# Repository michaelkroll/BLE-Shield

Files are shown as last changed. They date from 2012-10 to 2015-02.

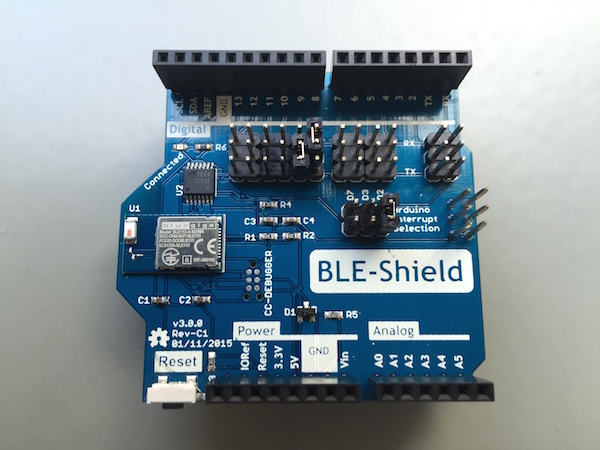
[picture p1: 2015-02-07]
docs/BLE-Shieldv3C1.jpg

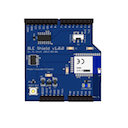
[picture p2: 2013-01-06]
iphone/BLE-Shield/BLE-Shield/ble-shield-list.png

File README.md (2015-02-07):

## BLE-Shield

The MIT License (MIT)
Copyright (c) 2012-2015 Dr. Michael Kroll
 
Permission is hereby granted, free of charge, to any person obtaining a copy of this software and associated 
documentation files (the "Software"), to deal in the Software without restriction, including without limitation 
the rights to use, copy, modify, merge, publish, distribute, sublicense, and/or sell copies of the Software, 
and to permit persons to whom the Software is furnished to do so, subject to the following conditions:
 
The above copyright notice and this permission notice shall be included in all copies or substantial portions of the Software.
 
THE SOFTWARE IS PROVIDED "AS IS", WITHOUT WARRANTY OF ANY KIND, EXPRESS OR IMPLIED, INCLUDING BUT NOT 
LIMITED TO THE WARRANTIES OF MERCHANTABILITY, FITNESS FOR A PARTICULAR PURPOSE AND NONINFRINGEMENT. IN 
NO EVENT SHALL THE AUTHORS OR COPYRIGHT HOLDERS BE LIABLE FOR ANY CLAIM, DAMAGES OR OTHER LIABILITY, 
WHETHER IN AN ACTION OF CONTRACT, TORT OR OTHERWISE, ARISING FROM, OUT OF OR IN CONNECTION WITH THE 
SOFTWARE OR THE USE OR OTHER DEALINGS IN THE SOFTWARE.

### Content

This repository contains the eagle design files as well as the firmware source code and precompiled hex files.
Moreover I added the Arduino Sketches from my blog to this repository.

### Latest Version

The Latest version of the BLE-Shield is v3.0.0 as illustrated in the image below.

(https://raw.github.com/michaelkroll/BLE-Shield/master/docs/BLE-Shieldv3C1.jpg)

#### Services and Characteristics of the BLE-Shield v3.0.0

The new BLE-Shield supports some new services and haracteristics. The RX and TX characteristics are not combined into one indicating Data characteristic
Moreover the Bluegiga OTA Service is supported enabling you to update the BLE-Shield over the air using e.g. the iOS App BLExplr.

##### BLE-Shield Service v3.0.0 (B4BDB998-8F4A-45F6-A407-6B48D79CFC2F)

###### Bluetooth Device Address Characteristic (B4BDB998-8F4B-45F6-A407-6B48D79CFC2F)

This characteristic is read only and used to retrieve the Bluetooth Device Address of the BLE113-M256k module.

###### Baudrate Characteristic (B4BDB998-8F4C-45F6-A407-6B48D79CFC2F)

This characteristic is read and write and used to set the BLE-Shields baudrate. The default baudrate is 9600 baud
It is a one byte characteristic. The following baudrates are suported and can be set using the following byte set to the
characteristic:

Baudrate  | Configuration Byte
--------- | ------------------
9600      | 0x00
14400     | 0x01
19200     | 0x02
28800     | 0x03
38400     | 0x04
57600     | 0x05
115200    | 0x06

###### Enable Connect LED characteristic (B4BDB998-8F4D-45F6-A407-6B48D79CFC2F)

This characteristic is used to control the connection LED on the BLE-Shield. The LED is per default off.
In order to change it's behavior write e.g. 0xff the the characteristic to make it lit on the next connection.

LED State | Configuration Byte
--------- | ------------------
OFF       | 0x00
ON        | 0xff

###### Data characteristic (B4BDB998-8F4E-45F6-A407-6B48D79CFC2F)

The new BLE-Shield v3.0.0 uses a Data characteristic to send and receive data. In order to support this
the characteristic is a write and indicate characteristic. On BLExplr it is no longer necessary to switch between
RX and TX characteristics. You can stay on the same screen to see data which is recevied while you are transmitting data.

##### Bluegiga OTA Service (1d14d6ee-fd63-4fa1-bfa4-8f47b42119f0)

This is the implementation of Bluegiga's OTA Service to update the firmware over the air.

###### Data characteristic (f7bf3564-fb6d-4e53-88a4-5e37e0326063)

Bluegiga OTA Control Characteristic

###### Data characteristic (984227f3-34fc-4045-a5d0-2c581f81a153)

Bluegiga OTA Data Characteristic

### Links
* http://www.mkroll.mobi
* http://forum.mkroll.mobi

### Notes:
* The Eagle design files are created using Eagle v5.11.0 - v7.1 depending on the version of the BLE-Shield. BLE-Shield v3.0.0 was designed with Eagle v7.1.0
* The Firmware v1.0.0 and v1.0.1 for the BLE112 module on the BLE-Shield was created and compiled for the Bluegiga BLE112 SDK v1.0.3 Build 43
* The Firmware v3.0.0 was developed using Bluegiga's BLE SDK v1.3.2 Build 122.
* The Arduino Sketches have been tested with Arduino 1.0.1
* the Arduino Sketched vor BLE-Shield v3.0.0 has been tested with Arduino v1.0.6 on OSX
* The .NETMF Sample has been tested with Microsoft Visual C# Express 2010, .NET Micro Framework SDK v4.2 and the Netduino SDK v4.2.2.0 (32-bit) running on a NetDuino2

## .NETMF support 
The latest addition to this repository is .NETMF support. With a little help of Thomas Amberg @tamberg I added a sample project for 
the NetDuino2 board available at http://www.netduino.com which shows how use the BLE-Shield with this platform.  

## BLE-Shield iPhone App for the BLE-Shield v1.0.0

The iPhone App was part of the BLE-Shield Kickstarter campaign https://www.kickstarter.com/projects/rowdyrobot/arduino-ble-shield-connecting-the-ios-and-the-ardu and only
supports the BLE-Shield v1.0.0 The BLE-Shield app provides access to the BLE-Shield Service and their characteristics. It's user interface is implemented like 
a chat application. The chart partners are the BLE-Shield and the iPhone, illustrated by small icons.

Once the BLE-Shield is connected, the application will automatically enable notifications on the RX characteristic. So whenever 
the BLE-Shield's 16 byte buffer is filled completely, the buffer will be notified to the iPhone. 

The app was developed using Xcode 4.5.2, iOS6 SDK and tested on an iPhone4S and iPhone5 running iOS6.0.1

*Screenshots*

 
. 
. 
. 
. 
. 
. 

### Used third party components

* BLEUtils taken from the TI SensorTag App, created by Ole Andreas Torvmark 
* MBProgressHUD created by Matej Bukovinski https://github.com/matej/MBProgressHUD
* PTSMessagingCell created by Ralph Grasser https://github.com/ppanopticon/PTSMessagingCell/

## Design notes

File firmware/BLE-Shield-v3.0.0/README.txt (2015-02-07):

The BLE113 pins are used as follows:
--------------------------------------------------

TX                 P0_4
RX                 P0_5

Connected LED      P0_0
Interrupt Pin      P0_1

--------------------------------------------------

The firmware is compiled against v 1.3.2 build 122

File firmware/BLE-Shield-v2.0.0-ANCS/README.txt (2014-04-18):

The BLE112 pins are used as follows:
--------------------------------------------------

TX                 P0_4
RX                 P0_5

Connected LED      P0_0
Interrupt Pin      P0_1

BLE Host Wakeup    P1_5
BLE Modules Wakeup P1_6

USB Port           P1_0
Boot to DFU        P1_1
--------------------------------------------------

The firmware is compiled against v 1.2.2 build 100

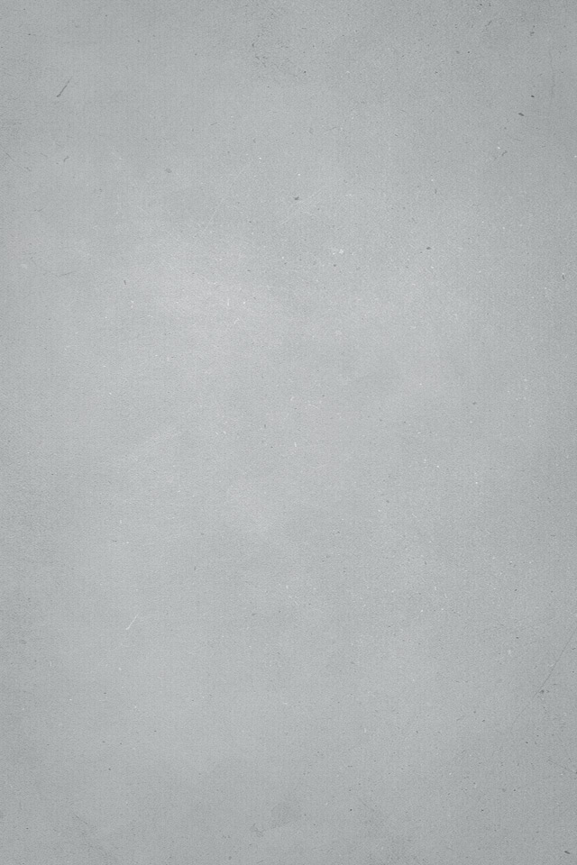
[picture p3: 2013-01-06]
iphone/BLE-Shield/BLE-Shield/background@2x.png

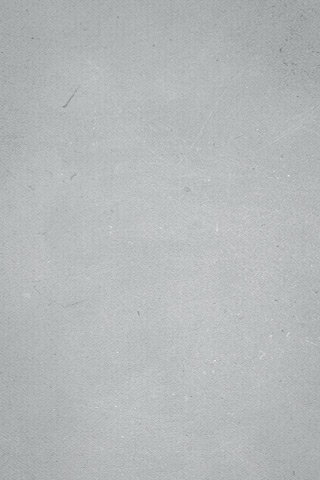
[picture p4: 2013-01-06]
iphone/BLE-Shield/BLE-Shield/background.png

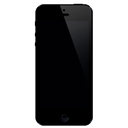
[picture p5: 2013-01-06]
iphone/BLE-Shield/BLE-Shield/iphone.png

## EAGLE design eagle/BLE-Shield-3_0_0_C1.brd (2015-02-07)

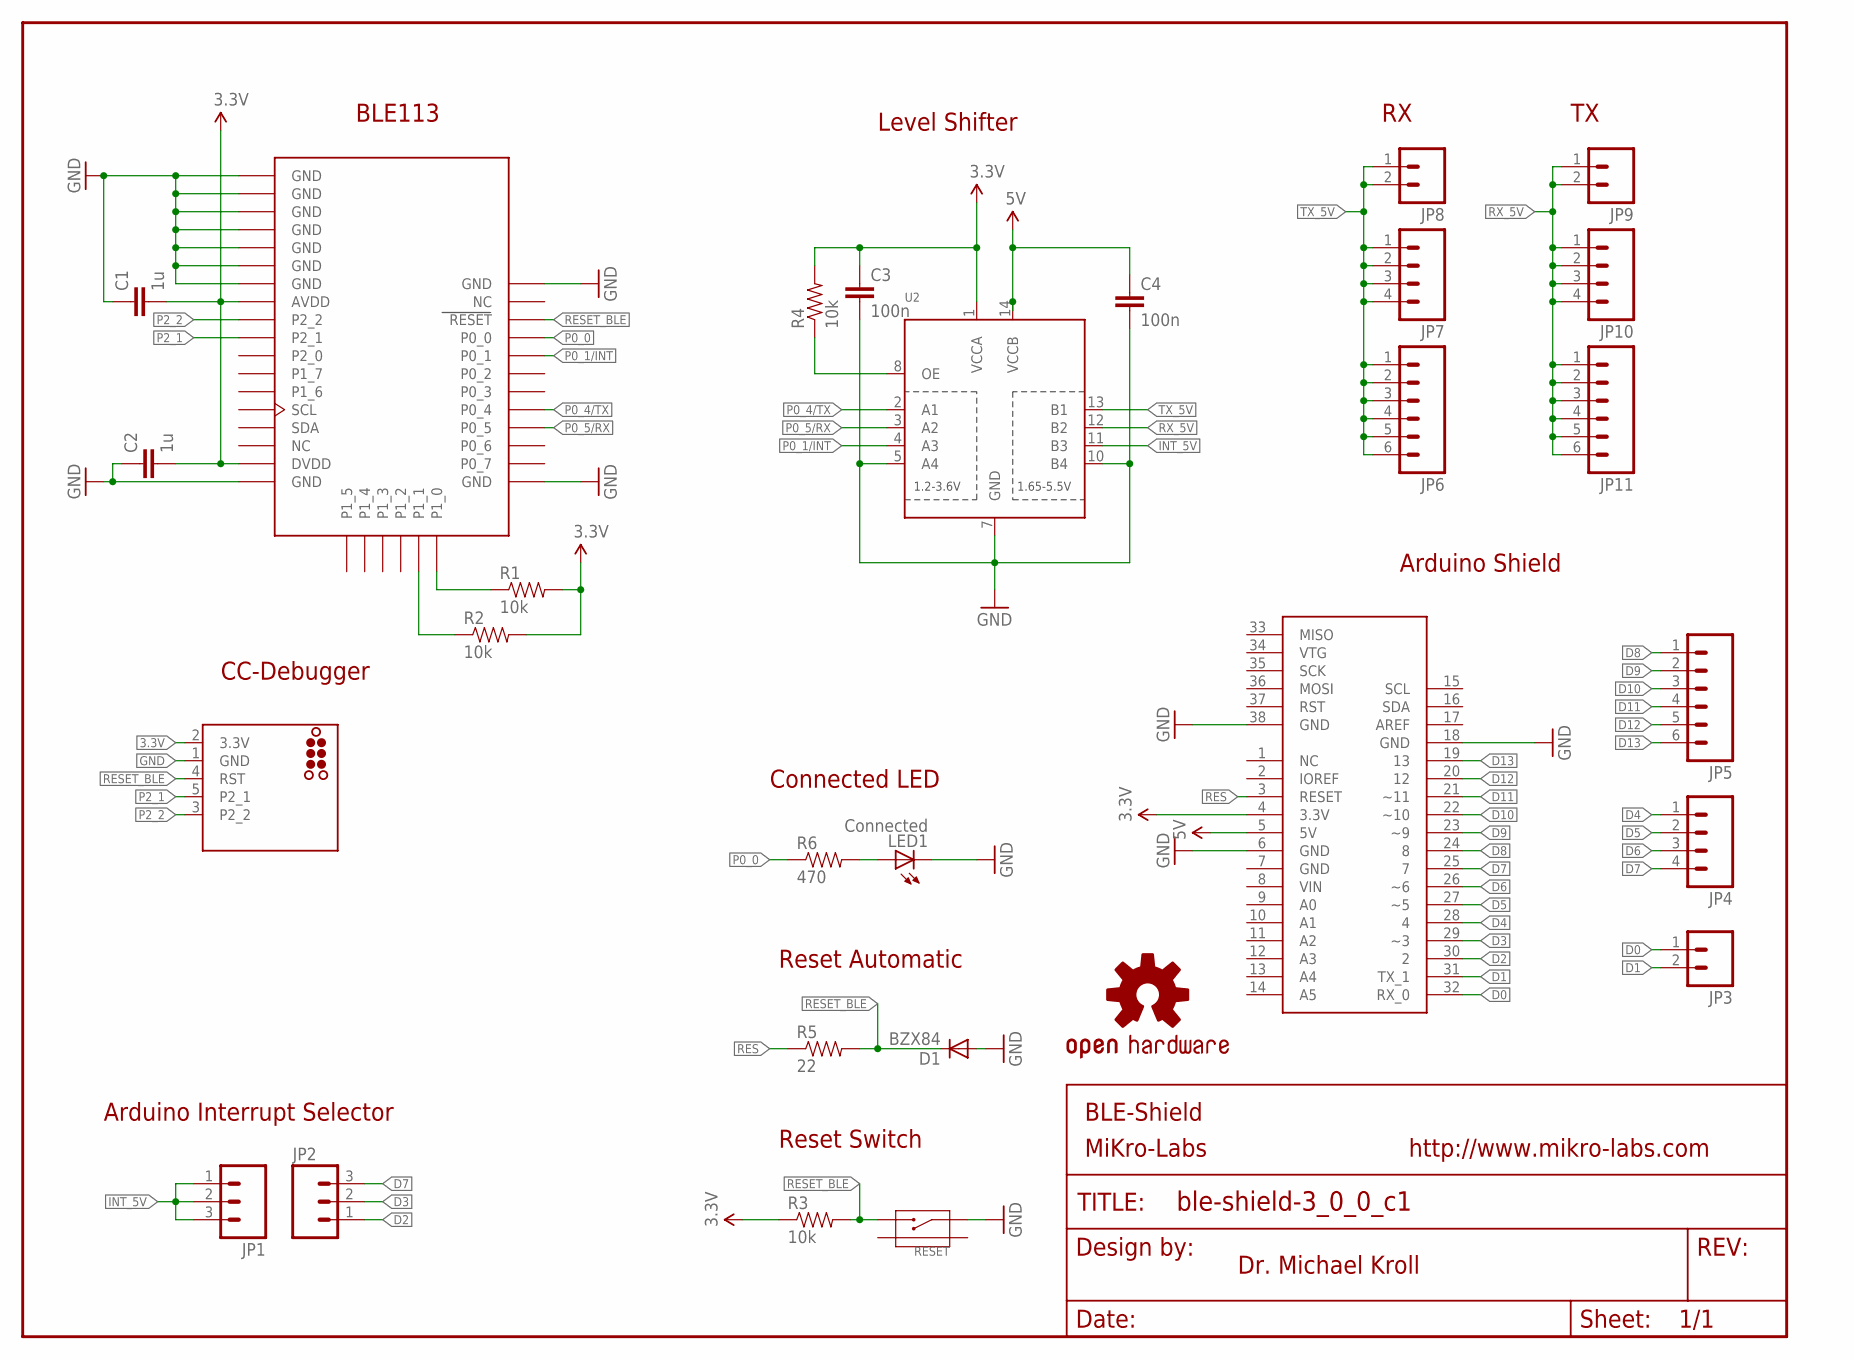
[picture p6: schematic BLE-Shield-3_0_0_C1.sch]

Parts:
C1, C2: 1u; 0603-CAP
C3, C4: 100n; 0603-CAP
CC-DEBUGGER: TC2030-CC-DEBUGGER; TC2030-MCP-NL
D1: BZX84; SOT23-3
FRAME1: FRAME-LETTER; CREATIVE_COMMONS
JP1, JP2: M03PTH; 1X03
JP3, JP8, JP9: M02PTH; 1X02
JP4, JP7, JP10: M04PTH; 1X04
JP5, JP6, JP11: M06SIP; 1X06
LED1: Connected; LED-0603
LOGO1: OSHW-LOGOS; OSHW-LOGO-S
R1, R2, R3, R4: 10k; 0603-RES
R5: 22; 0603-RES
R6: 470; 0603-RES
RESET: BUTTON-2P-REINFORCE-3100060P1; 4P-SMD-7.0X3.5X3.5H-90D
U1: BLE113-A-VISUAL; BLE113-A
U2: TXB0104PWR; TSSOP14
U$1: ARDUINO_UNO_SHIELD_ICSP_PADS_ONLY; ICSP_PADS_ONLY

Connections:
3.3V: C1.2, C2.2, C3.1, CC-DEBUGGER.2 (3.3V), R1.2, R2.2, R3.1, R4.2, U1.AVDD, U1.DVDD, U2.1 (VCCA), U$1.4 (3.3V)
5V: C4.1, U2.14 (VCCB), U$1.5 (5V)
D0: JP3.1, U$1.32 (RX_0)
D1: JP3.2, U$1.31 (TX_1)
D2: JP2.1, U$1.30 (2)
D3: JP2.2, U$1.29 (~3)
D4: JP4.1, U$1.28 (4)
D5: JP4.2, U$1.27 (~5)
D6: JP4.3, U$1.26 (~6)
D7: JP2.3, JP4.4, U$1.25 (7)
D8: JP5.1, U$1.24 (8)
D9: JP5.2, U$1.23 (~9)
D10: JP5.3, U$1.22 (~10)
D11: JP5.4, U$1.21 (~11)
D12: JP5.5, U$1.20 (12)
D13: JP5.6, U$1.19 (13)
GND: C1.1, C2.1, C3.2, C4.2, CC-DEBUGGER.1 (GND), D1.1 (A), LED1.C, RESET.1, U1.GND, U1.GND@2 (GND), U1.GND@3 (GND), U1.GND@4 (GND), U1.GND@5 (GND), U1.GND@6 (GND), U1.GND@7 (GND), U1.GND@8 (GND), U1.GND@9 (GND), U1.GND@10 (GND), U2.5 (A4), U2.7 (GND), U2.10 (B4), U$1.6 (GND), U$1.18 (GND), U$1.38 (GND)
INT_5V: JP1.1, JP1.2, JP1.3, U2.11 (B3)
unnamed: LED1.A, R6.2
unnamed: R4.1, U2.8 (OE)
unnamed: R1.1, U1.P1_0
unnamed: R2.1, U1.P1_1
P0_0: R6.1, U1.P0_0
P0_1/INT: U1.P0_1, U2.4 (A3)
P0_4/TX: U1.P0_4, U2.2 (A1)
P0_5/RX: U1.P0_5, U2.3 (A2)
P2_1: CC-DEBUGGER.5 (P2_1), U1.P2_1
P2_2: CC-DEBUGGER.3 (P2_2), U1.P2_2
RES: R5.1, U$1.3 (RESET)
RESET_BLE: CC-DEBUGGER.4 (RST), D1.3 (C), R3.2, R5.2, RESET.2, U1.RESET
RX_5V: JP9.1, JP9.2, JP10.1, JP10.2, JP10.3, JP10.4, JP11.1, JP11.2, JP11.3, JP11.4, JP11.5, JP11.6, U2.12 (B2)
TX_5V: JP6.1, JP6.2, JP6.3, JP6.4, JP6.5, JP6.6, JP7.1, JP7.2, JP7.3, JP7.4, JP8.1, JP8.2, U2.13 (B1)

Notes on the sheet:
BLE113
CC-Debugger
Arduino Shield
Level Shifter
Reset Switch
Reset Automatic
Connected LED
Arduino Interrupt Selector
BLE-Shield
MiKro-Labs
http://www.mikro-labs.com
Dr. Michael Kroll

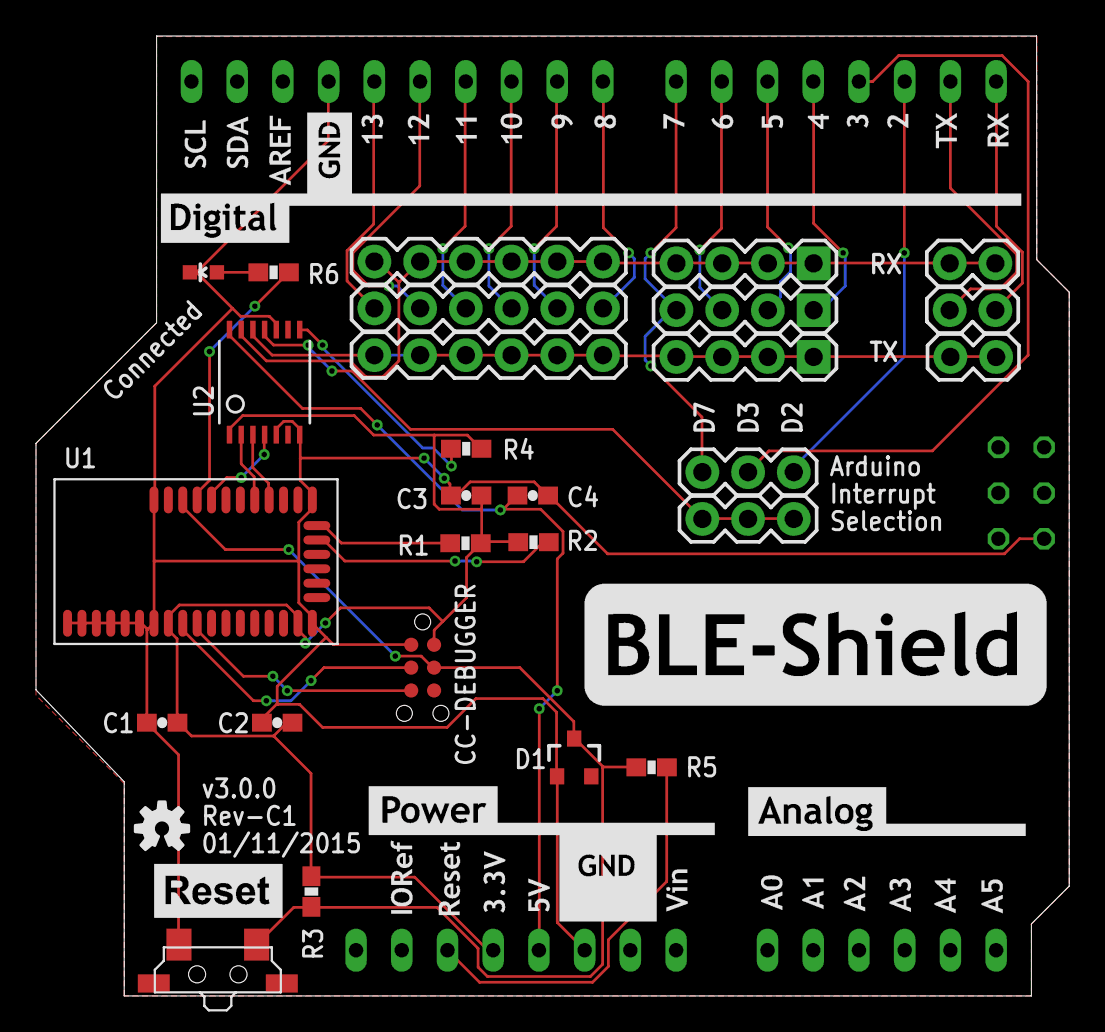
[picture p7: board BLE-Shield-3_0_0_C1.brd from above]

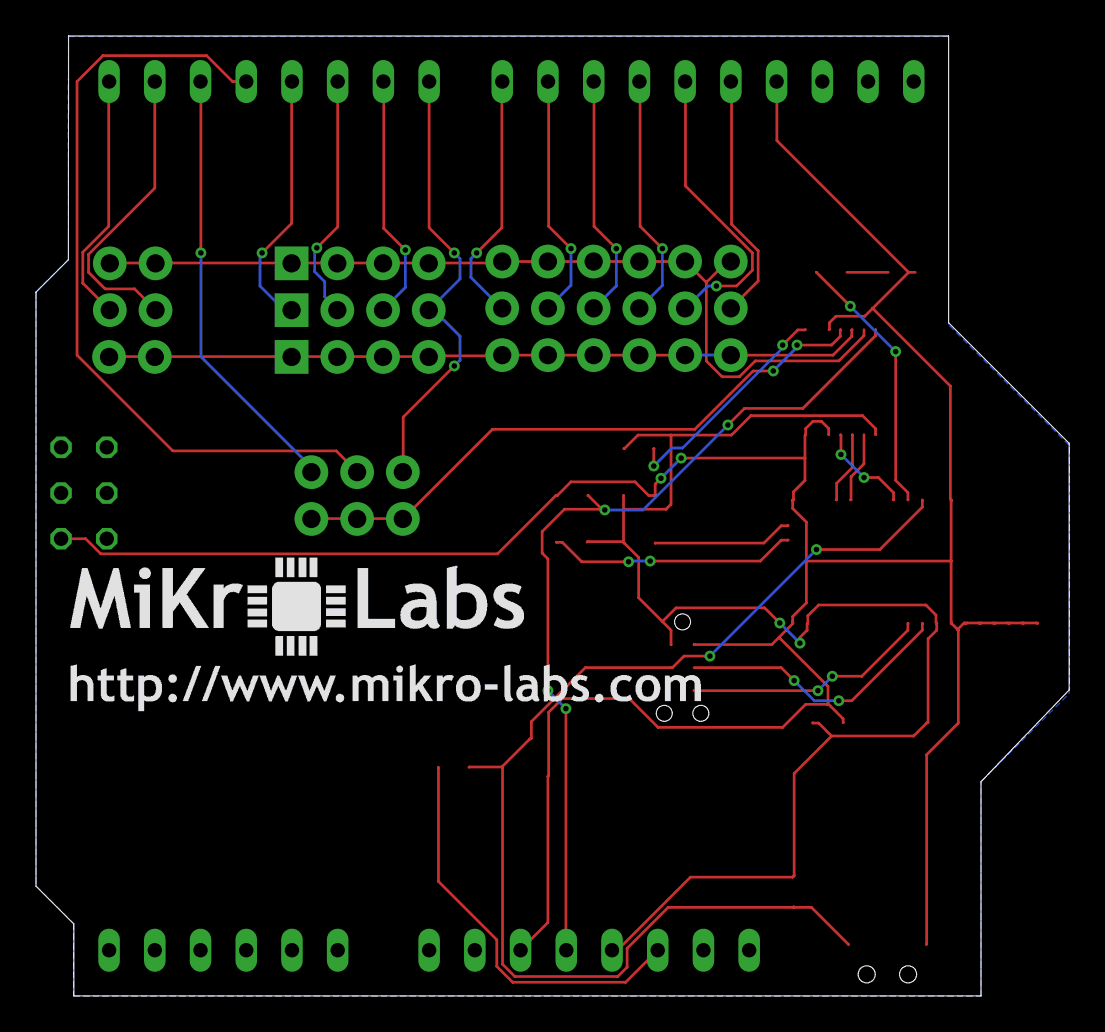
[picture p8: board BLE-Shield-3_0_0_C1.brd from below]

Board: 4 copper layers, 57.4 x 53.3 mm, 36 parts (2 on the bottom side), 32 nets.

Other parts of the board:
U$2: DIGITAL
U$3: POWER-ANALOG
U$4: MIKROLABS-URL
U$5: MIKROLABS-LOGO
U$6: BLE-SHIELD
U$7: RESET

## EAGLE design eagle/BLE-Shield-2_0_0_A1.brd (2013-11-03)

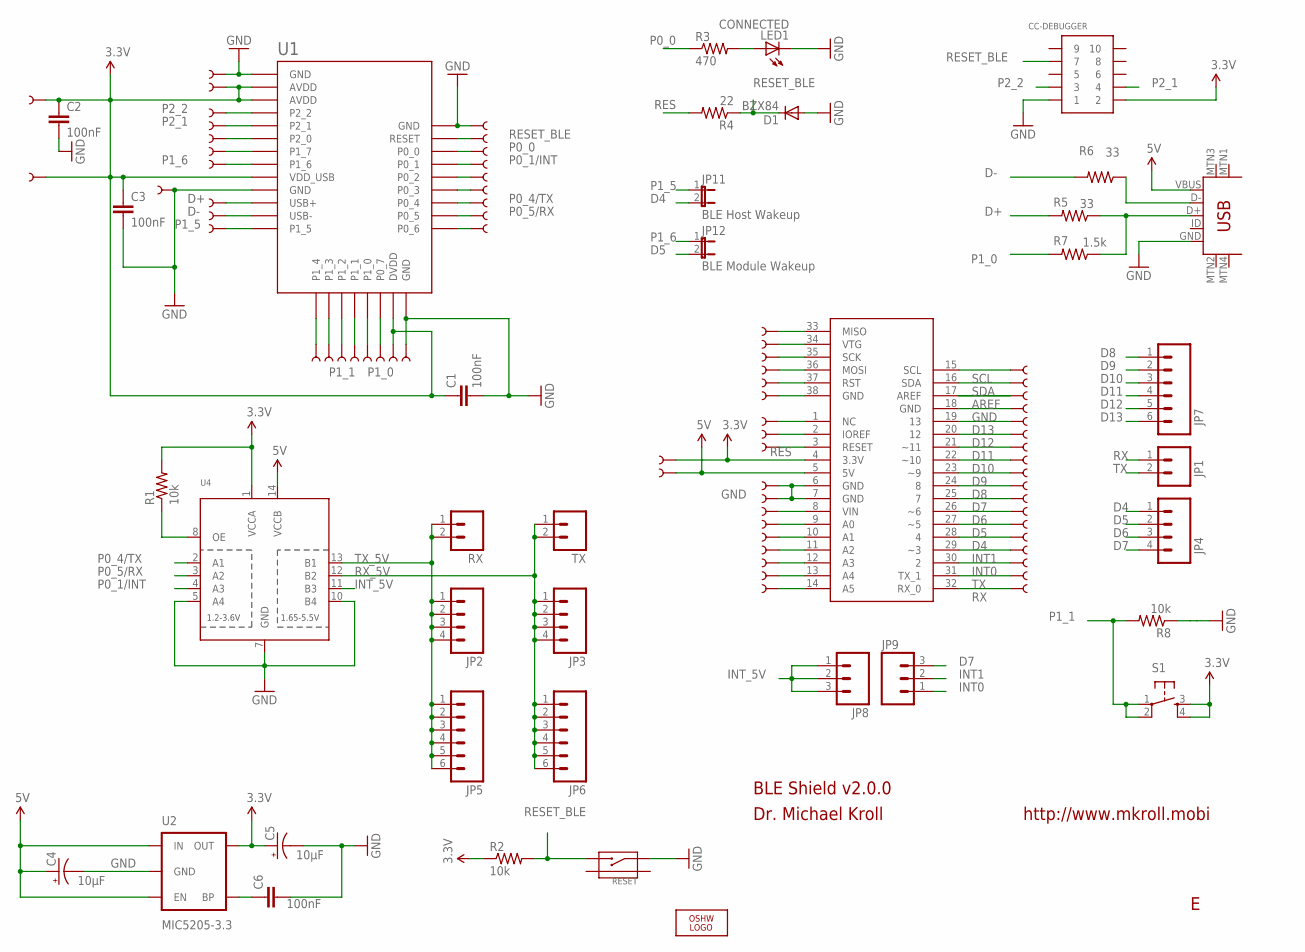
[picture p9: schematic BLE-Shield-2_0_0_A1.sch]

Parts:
C1, C2, C3, C6: 100nF; 0603-CAP
C4, C5: 10µF; EIA3216
CC-DEBUGGER: CONN_5-2-FTSH-V; FTSH-105-DV
D1: BZX84; SOT23-3
JP1: M02PTH; 1X02
JP2, JP3, JP4: M04PTH; 1X04
JP5, JP6, JP7: M06SIP; 1X06
JP8, JP9: M03PTH; 1X03
JP11: BLE Host Wakeup; SJ_2S-NO-NS
JP12: BLE Module Wakeup; SJ_2S-NO-NS
LED1: CONNECTED; LED-0603
LOGO1: LOGO-OSHW-FILLX0200-NT; OSHW_FILLX200_NOTEXT
R1, R2, R8: 10k; 0603-RES
R3: 470; 0603-RES
R4: 22; 0603-RES
R5, R6: 33; 0603-RES
R7: 1.5k; 0603-RES
RESET: BUTTON-2P-REINFORCE-3100060P1; 4P-SMD-7.0X3.5X3.5H-90D
RX: M02PTH; 1X02
S1: TAC_SWITCHSMD; TACTILE_SWITCH_SMD
TP1, TP2, TP3, TP4, TP5, TP6, TP7, TP8, TP9, TP10, TP11, TP12, TP13, TP14, TP15, TP16, TP17, TP18, TP19, TP20, TP21, TP22, TP23, TP24, TP25, TP26, TP27, TP28, TP29, TP30, TP31, TP32, TP33, TP34, TP35, TP36, TP37, TP38, TP39, TP40, TP41, TP42, TP43, TP44, TP45, TP46, TP47, TP48, TP49, TP50, TP51, TP52, TP53, TP54, TP55, TP56, TP57, TP58, TP59, TP60, TP61, TP62, TP63, TP64, TP65, TP66, TP67, TP68: TEST-POINT3X5; PAD.03X.05
TX: M02PTH; 1X02
U1: BLE112-A-VISUAL; BLE112-A
U2: MIC5205-3.3; SOT23-5
U4: TXB0104PWR; TSSOP14
U$5: ARDUINO_UNO_SHIELD_ICSP_PADS_ONLY; ICSP_PADS_ONLY
U$6: USB-MINIB-5PIN; USB-MINIB

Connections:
3.3V: C1.1, C2.1, C3.1, C5.A (+), CC-DEBUGGER.2, R1.2, R2.1, S1.3, S1.4, TP29.P$1, TP45.P$1, TP57.P$1, TP58.P$1, TP64.P$1, U1.AVDD1 (AVDD), U1.AVDD2 (AVDD), U1.DVDD, U1.VDD_USB, U2.5 (OUT), U4.1 (VCCA), U$5.4 (3.3V)
5V: C4.A (+), TP46.P$1, U2.1 (IN), U2.3 (EN), U4.14 (VCCB), U$5.5 (5V), U$6.VBUS
AREF: TP3.P$1, U$5.17 (AREF)
D4: JP4.1, JP11.2, TP14.P$1, U$5.28 (4)
D5: JP4.2, JP12.2, TP13.P$1, U$5.27 (~5)
D6: JP4.3, TP12.P$1, U$5.26 (~6)
D7: JP4.4, JP9.3, TP11.P$1, U$5.25 (7)
D8: JP7.1, TP10.P$1, U$5.24 (8)
D9: JP7.2, TP9.P$1, U$5.23 (~9)
D10: JP7.3, TP8.P$1, U$5.22 (~10)
D11: JP7.4, TP7.P$1, U$5.21 (~11)
D12: JP7.5, TP6.P$1, U$5.20 (12)
D13: JP7.6, TP5.P$1, U$5.19 (13)
D+: R5.2, TP66.P$1, U1.USB+
D-: R6.2, TP67.P$1, U1.USB-
GND: C1.2, C2.2, C3.2, C4.C (-), C5.C (-), C6.2, CC-DEBUGGER.1, D1.1 (A), LED1.C, R8.1, RESET.1, TP4.P$1, TP19.P$1, TP28.P$1, TP47.P$1, TP48.P$1, TP54.P$1, TP65.P$1, U1.GND1 (GND), U1.GND2 (GND), U1.GND3 (GND), U1.GND4 (GND), U2.2 (GND), U4.5 (A4), U4.7 (GND), U4.10 (B4), U$5.6 (GND), U$5.7 (GND), U$5.18 (GND), U$6.GND
INT0: JP9.1, TP16.P$1, U$5.30 (2)
INT1: JP9.2, TP15.P$1, U$5.29 (~3)
INT_5V: JP8.1, JP8.2, JP8.3, U4.11 (B3)
unnamed: TP53.P$1, U$5.12 (A3)
unnamed: C6.1, U2.4 (BP)
unnamed: TP56.P$1, U$5.14 (A5)
unnamed: LED1.A, R3.2
unnamed: TP55.P$1, U$5.13 (A4)
unnamed: TP52.P$1, U$5.11 (A2)
unnamed: TP51.P$1, U$5.10 (A1)
unnamed: TP50.P$1, U$5.9 (A0)
unnamed: TP49.P$1, U$5.8 (VIN)
unnamed: R5.1, R7.1, U$6.D+
unnamed: TP43.P$1, U$5.2 (IOREF)
unnamed: TP27.P$1, U1.P0_6
unnamed: TP35.P$1, U1.P1_4
unnamed: TP24.P$1, U1.P0_3
unnamed: TP23.P$1, U1.P0_2
unnamed: TP42.P$1, U$5.1 (NC)
unnamed: TP34.P$1, U1.P1_3
unnamed: TP33.P$1, U1.P1_2
unnamed: TP30.P$1, U1.P0_7
unnamed: TP41.P$1, U$5.38 (GND)
unnamed: TP40.P$1, U$5.37 (RST)
unnamed: TP39.P$1, U$5.36 (MOSI)
unnamed: TP38.P$1, U$5.35 (SCK)
unnamed: TP37.P$1, U$5.34 (VTG)
unnamed: TP36.P$1, U$5.33 (MISO)
unnamed: R6.1, U$6.D-
unnamed: TP61.P$1, U1.P2_0
unnamed: TP62.P$1, U1.P1_7
unnamed: R1.1, U4.8 (OE)
P0_0: R3.1, TP21.P$1, U1.P0_0
P0_1/INT: TP22.P$1, U1.P0_1, U4.4 (A3)
P0_4/TX: TP25.P$1, U1.P0_4, U4.2 (A1)
P0_5/RX: TP26.P$1, U1.P0_5, U4.3 (A2)
P1_0: R7.2, TP31.P$1, U1.P1_0
P1_1: R8.2, S1.1, S1.2, TP32.P$1, U1.P1_1
P1_5: JP11.1, TP68.P$1, U1.P1_5
P1_6: JP12.1, TP63.P$1, U1.P1_6
P2_1: CC-DEBUGGER.4, TP60.P$1, U1.P2_1
P2_2: CC-DEBUGGER.3, TP59.P$1, U1.P2_2
RES: R4.2, TP44.P$1, U$5.3 (RESET)
RESET_BLE: CC-DEBUGGER.7, D1.3 (C), R2.2, R4.1, RESET.2, TP20.P$1, U1.RESET
RX: JP1.1, TP18.P$1, U$5.32 (RX_0)
RX_5V: JP3.1, JP3.2, JP3.3, JP3.4, JP6.1, JP6.2, JP6.3, JP6.4, JP6.5, JP6.6, TX.1, TX.2, U4.12 (B2)
SCL: TP1.P$1, U$5.15 (SCL)
SDA: TP2.P$1, U$5.16 (SDA)
TX: JP1.2, TP17.P$1, U$5.31 (TX_1)
TX_5V: JP2.1, JP2.2, JP2.3, JP2.4, JP5.1, JP5.2, JP5.3, JP5.4, JP5.5, JP5.6, RX.1, RX.2, U4.13 (B1)

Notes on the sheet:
BLE Shield v2.0.0
Dr. Michael Kroll
http://www.mkroll.mobi

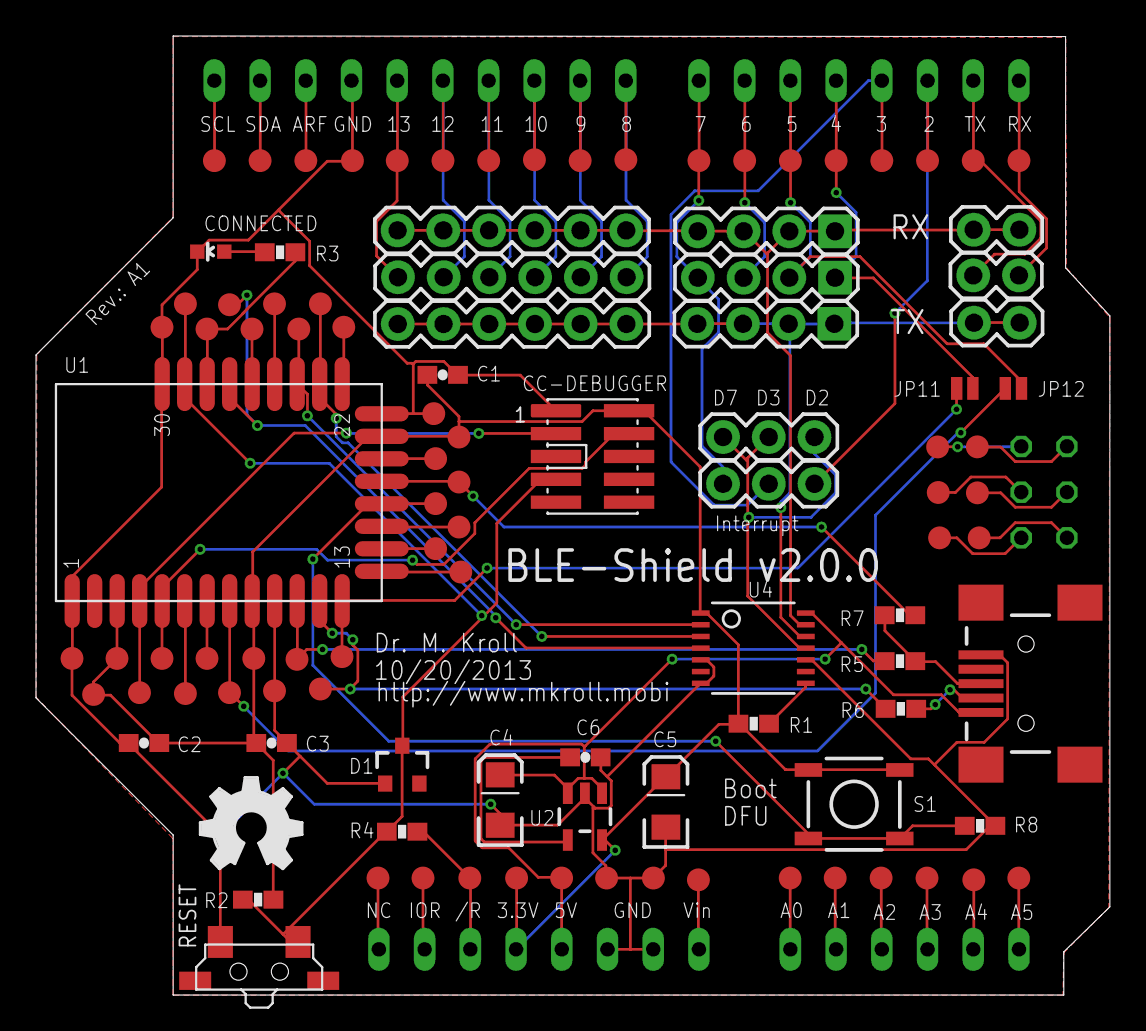
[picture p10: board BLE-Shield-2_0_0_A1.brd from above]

Board: 4 copper layers, 59.7 x 53.3 mm, 106 parts (0 on the bottom side), 66 nets.

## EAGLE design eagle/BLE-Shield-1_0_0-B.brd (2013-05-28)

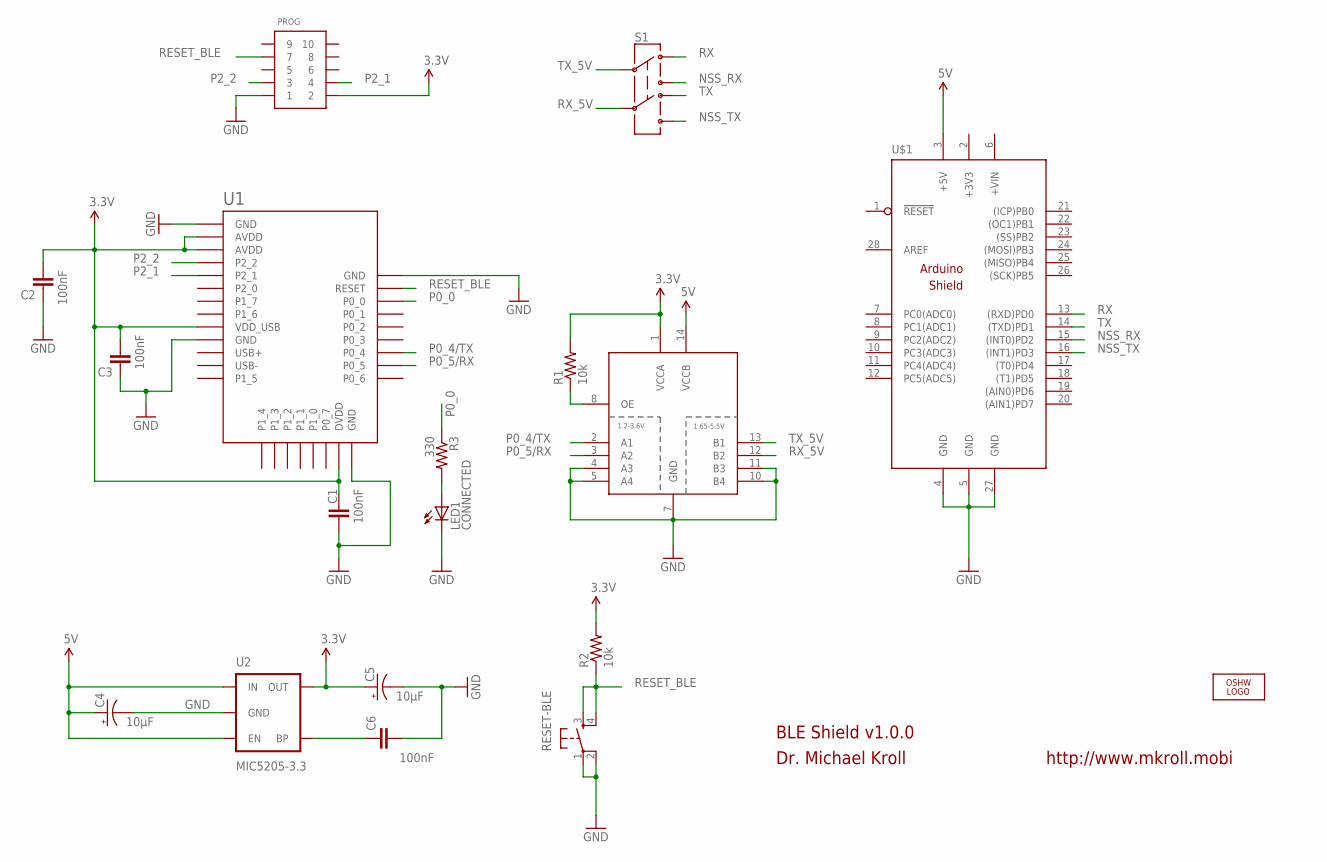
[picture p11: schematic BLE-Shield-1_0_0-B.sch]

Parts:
C1, C2, C3, C6: 100nF; 1206
C4, C5: 10µF; EIA3216
LED1: CONNECTED; LED-1206-BLUE
LOGO1: LOGO-OSHW-FILLX0200-NT; OSHW_FILLX200_NOTEXT
PROG: CONN_5-2-FTSH-V; FTSH-105-DV
R1, R2: 10k; 0805
R3: 330; 0805
RESET-BLE: TAC_SWITCHSMD; TACTILE_SWITCH_SMD
S1: SWITCH-DPDTSMD; AYZ0202
U1: BLE112-A-VISUAL; BLE112-A
U2: MIC5205-3.3; SOT23-5
U3: TXB0104DR; SO14
U$1: ARDUINO_SHIELD

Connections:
3.3V: C1.2, C2.2, C3.2, C5.A (+), PROG.2, R1.2, R2.2, U1.AVDD1 (AVDD), U1.AVDD2 (AVDD), U1.DVDD, U1.VDD_USB, U2.5 (OUT), U3.1 (VCCA)
5V: C4.A (+), U2.1 (IN), U2.3 (EN), U3.14 (VCCB), U$1.3 (+5V)
+3V3: U$1.2 (+3V3)
GND: C1.1, C2.1, C3.1, C4.C (-), C5.C (-), C6.2, LED1.C, PROG.1, RESET-BLE.1, RESET-BLE.2, U1.GND1 (GND), U1.GND2 (GND), U1.GND3 (GND), U1.GND4 (GND), U2.2 (GND), U3.4 (A3), U3.5 (A4), U3.7 (GND), U3.10 (B4), U3.11 (B3), U$1.4 (GND), U$1.5 (GND), U$1.27 (GND)
unnamed: C6.1, U2.4 (BP)
unnamed: LED1.A, R3.2
unnamed: R1.1, U3.8 (OE)
NSS_RX: S1.3, U$1.15 ((INT0)PD2)
NSS_TX: S1.6, U$1.16 ((INT1)PD3)
P0_0: R3.1, U1.P0_0
P0_4/TX: U1.P0_4, U3.2 (A1)
P0_5/RX: U1.P0_5, U3.3 (A2)
P2_1: PROG.4, U1.P2_1
P2_2: PROG.3, U1.P2_2
RESET_BLE: PROG.7, R2.1, RESET-BLE.3, RESET-BLE.4, U1.RESET
RX: S1.1, U$1.13 ((RXD)PD0)
RX_5V: S1.5, U3.12 (B2)
TX: S1.4, U$1.14 ((TXD)PD1)
TX_5V: S1.2, U3.13 (B1)

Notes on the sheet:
BLE Shield v1.0.0
Dr. Michael Kroll
http://www.mkroll.mobi

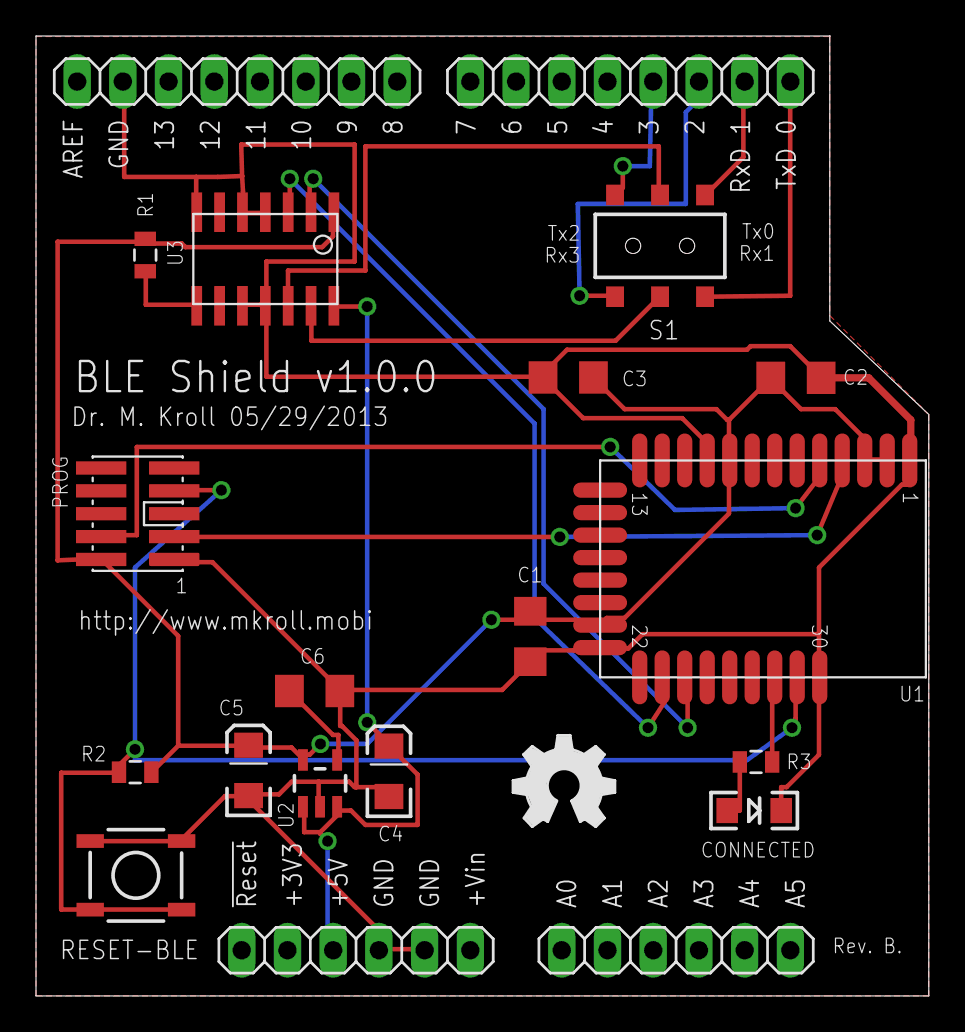
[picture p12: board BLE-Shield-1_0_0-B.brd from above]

Board: 2 copper layers, 49.6 x 53.3 mm, 18 parts (0 on the bottom side), 18 nets.

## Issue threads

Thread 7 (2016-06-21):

Eagle Files Adafruit ESP8266 Feather.brd and .sch

PCB1999, 2016-06-21:
Hi, I'm at the link (https://github.com/adafruit/Adafruit-Feather-ESP8266-HUZZAH-PCB) where the .brd and .sch files are.   When I open either one, I don't see the board or schematic, just text showing layers, cream, etc.  Can someone give me some advice on how to bring these two files into Eagle 5.12 Professional?

Thank you,

Brian

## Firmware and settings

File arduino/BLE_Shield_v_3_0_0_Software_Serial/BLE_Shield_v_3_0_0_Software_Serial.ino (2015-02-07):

/*
 * BLE Shield SoftSerial Test Sketch for Arduino 1.0.6
 * v3.0.0 2015-02-06
 * 
 * Copyright (c) 2012-2015 Dr. Michael Kroll
 *
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
 * http://www.mkroll.mobi
 * http://forum.mkroll.mobi
 */
#include <SoftwareSerial.h>

// In order to not interfear with the USB serial console
// we configure the BLE-Shields serial lines to be available
// through SoftwareSerial on pins D8 and D9. 
// Please set the jumpers
// to RX -> D8 and TX -> D9
SoftwareSerial bleShield(8,9);
boolean connected;

void setup()   {

  // On the Arduino Uno, the Serial port is mapped to the USB Cable
  // and available in pins D0 D1.
  // We set it to 9600 baud.
  Serial.begin(9600);
  Serial.print("BLE-Shield v3.0.0 Sketch setup...");

  // Set the data rate for the SoftwareSerial port
  // The BLE-Shield v3.0.0 is running at 9600 since this
  // is the default baudrate for the BLE-Shield v3.0.0 
  bleShield.begin(9600);
  // The BLE-Shield v3.0.0 is not only litting up the blue LED on connection, 
  // but raising and lowering an interrupt on the Arduino.
  // Finally you are able to see the connected state on the Arduino :-)
  // Here we attach the interrupt according to the spec at   
  // http://arduino.cc/en/Reference/attachInterrupt
  // The interrupt jumper has to be set to D2
  attachInterrupt(0, connection, CHANGE);
  Serial.println(" done.");
  connected = false;
}


void loop() // run over and over
{
  // Wait for Data on the serial console and submit it to the
  // BLE-Shield byte per byte. there is no longer a buffer involved.
  if (Serial.available()) {
    int ch = Serial.read();
    char c = char(ch);
    Serial.print(c);
    bleShield.print(c);
  }
  
  // Wait for data send from the iPhone and print it to the serial console.
  // That's it. Quite simple.
  if (bleShield.available()) {
    Serial.write(bleShield.read());
  }
}

// This method is called if the connection state changes. 
// When a connection is established, the Interrupt will be set to high, and
// set to low, once the BLE-Shield is disconnected.
void connection() {
  connected = !connected;
  if (connected) {
    Serial.println("BLE-Shield Connected = true");
  }
  else {
    Serial.println("BLE-Shield Connected = false");  
  }
}

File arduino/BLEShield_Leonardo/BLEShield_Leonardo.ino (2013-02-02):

/*
 * BLE Shield Test Sketch for Arduino 1.0.3
 * Sketch for Arduino Leonardo
 * by Dr. Michael Kroll 2013
 * v1.0.0 2013-02-02
 */

long previousMillis = 0; 
long interval = 1000; 

void setup()  
{
  // set the data rate for the SoftwareSerial port
  Serial.begin(19200);
  Serial1.begin(19200);
  randomSeed(analogRead(0));  
}

void loop() // run over and over
{
  
  unsigned long currentMillis = millis();
 
  if(currentMillis - previousMillis > interval) {
    previousMillis = currentMillis;   
      
    int randNumber1 = random(255);
    int randNumber2 = random(255);
    int randNumber3 = random(255);
    int randNumber4 = random(255);
    
    Serial1.write(randNumber1);
    Serial1.write(randNumber2);
    Serial1.write(randNumber3);
    Serial1.write(randNumber4);    
  }
  
  if (Serial1.available()) {
    Serial.write(Serial1.read());
  }
}

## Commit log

2012-10-21 Eagle design files added.
    [BLE-Shield-1_0_0.brd, BLE-Shield-1_0_0.sch]
2012-10-21 PDF schematic added.
2012-10-25 Arduino Test Sketches added.
2013-05-28 New firmware for the BLE-Shield v1.0.0 Revision B with slightly modified via positions and silkscreen adjustments.
    [BLE-Shield-1_0_0-B.brd, BLE-Shield-1_0_0-B.sch]
2013-10-20 Two new sample sketches added for Arduino Leonardo and Arduino Uno.
2013-11-03 Removed the old firmware. Added Eagle Design files.
    [BLE-Shield-2_0_0_A1.brd, BLE-Shield-2_0_0_A1.sch]
2013-12-08 Sample sketch for BLE-Shield v1.0.0 with Firmware v1.1.0 added.
2014-04-18 initial version of the BLE-Shield v2.0.0 ANCS Firmware added. It is still under development, but notifications are already received on the Arduino. Access methods to get the title, message, appid etc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
2014-04-18 Initial work in progress version of an ANCS library for Arduino added.
2014-10-13 new projects for the BLE-Shield v3.0.0 added. Still WIP since the boards are not yet final and the firmware and hardware for the BLE-Shield v3.0.0 LR needs to be tested regarding range.
2015-02-07 Initial version of the v3.0.0 firmware finished. Added the eagle design files of revision C1 and the Arduino Sample Sketch.
    [BLE-Shield-3_0_0_C1.brd, BLE-Shield-3_0_0_C1.sch]

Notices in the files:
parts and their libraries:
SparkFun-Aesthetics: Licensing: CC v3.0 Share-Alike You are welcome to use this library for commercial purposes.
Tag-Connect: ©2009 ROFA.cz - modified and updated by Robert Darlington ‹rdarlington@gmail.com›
